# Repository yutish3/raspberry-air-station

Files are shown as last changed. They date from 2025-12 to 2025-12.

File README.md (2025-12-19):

# raspberry-air-station
this is a small project. how it overall works is raspberry pie takes data from sen 54 sensor and displayes it on e ink display and on a password protected website

deeper explanation :- it runs on a raspberry pi 4 and it uses sen 54 to get the info like (PM1.0, PM2.5, PM4.0, PM10, VOC Index, Temperature, Humidity) and display it on the e ink display which updates every 10 second and in background it is also hosting a website so you can change image on the aqi sensor like black and white art from phone and can also access the aqi data from website and the website is password protected. there is also an physical touch sensor using which you can switch between what to show on e ink display photo or the data 

i decided to make this project so i can have it as my personal home air station as i live in delhi (avg 300+ aqi) i will prob use it a lot to check the aqi and it can give an overall glimps of if i should leave the state for now or not 

# BOM
1. Sensirion SEN54 - 1 - Air Quality Sensor
2. Raspberry Pi 4 Model B (4GB RAM) - 1 - main controller
3. Waveshare 4.2-inch e-Paper Module (SPI) - 1 - display (400x300)
4. SmartElex Logic Level Converter (Bi-Directional) - 1 - 4 channel bi direction converter (3.3v - 5v)
5. Raspberry Pi 4 Power Supply (5.1V 3A Type-C) - 1 - power supply
6. Male Headers (1x40 Pin, 2.54mm) - 1
7. Female Headers (2x20 Pin, 2.54mm) - 1 
8. TTP223 Touch Sensor (Module) - 1 - input sensor
9 sd card 32 gb - 1 - for storage

i found all the components on robu except SEN54 which i found on Tanotis

# BOM images









# CAD FILE





# PCM




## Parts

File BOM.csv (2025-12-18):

part name | quantity | vendor | approx cost (inr)
raspberry pi 4 model b with 4gb ram | 1 | robu.in | 6369.00
sensirion sen55 particle & gas sensor | 1 | tanotis | 3 | 845.92
waveshare 4.2-inch e-paper module | 1 | robu.in | 2825.00
official raspberry pi micro sd card (64gb) | 1 | robu.in | 899.00
raspberry pi power adapter (5.1v 3a) | 1 | robu.in | 349.30
smartelex logic level converter (bi-directional) | 1 | robu.in | 39.00
ttp223b touch sensor | 1 | robu.in | 15.00
2.54mm 2x20 pin female header | 1 | robu.in | 10.00
custom pcb manufacturing (seeed studio) | 5 | seeed studio | $4.90
pcb shipping (dhl) | 1 | seeed studio | $28.48
robu.in | ₹ 10 | 506
tanotis.com | ₹3 | 846
seedstudio.com | $33.38

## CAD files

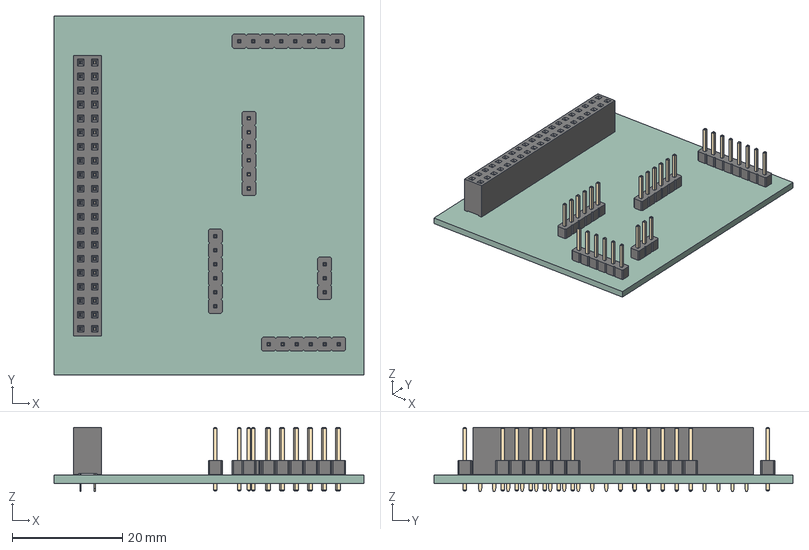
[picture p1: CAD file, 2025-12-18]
Pcb/AeroInk_HAT.step
56.1 x 65.0 x 11.6 mm
PinSocket_2x20_P2.54mm_Vertical
PinHeader_1x06_P2.54mm_Vertical x 3
PinHeader_1x08_P2.54mm_Vertical
PinHeader_1x03_P2.54mm_Vertical
AQI SEN 54_PCB

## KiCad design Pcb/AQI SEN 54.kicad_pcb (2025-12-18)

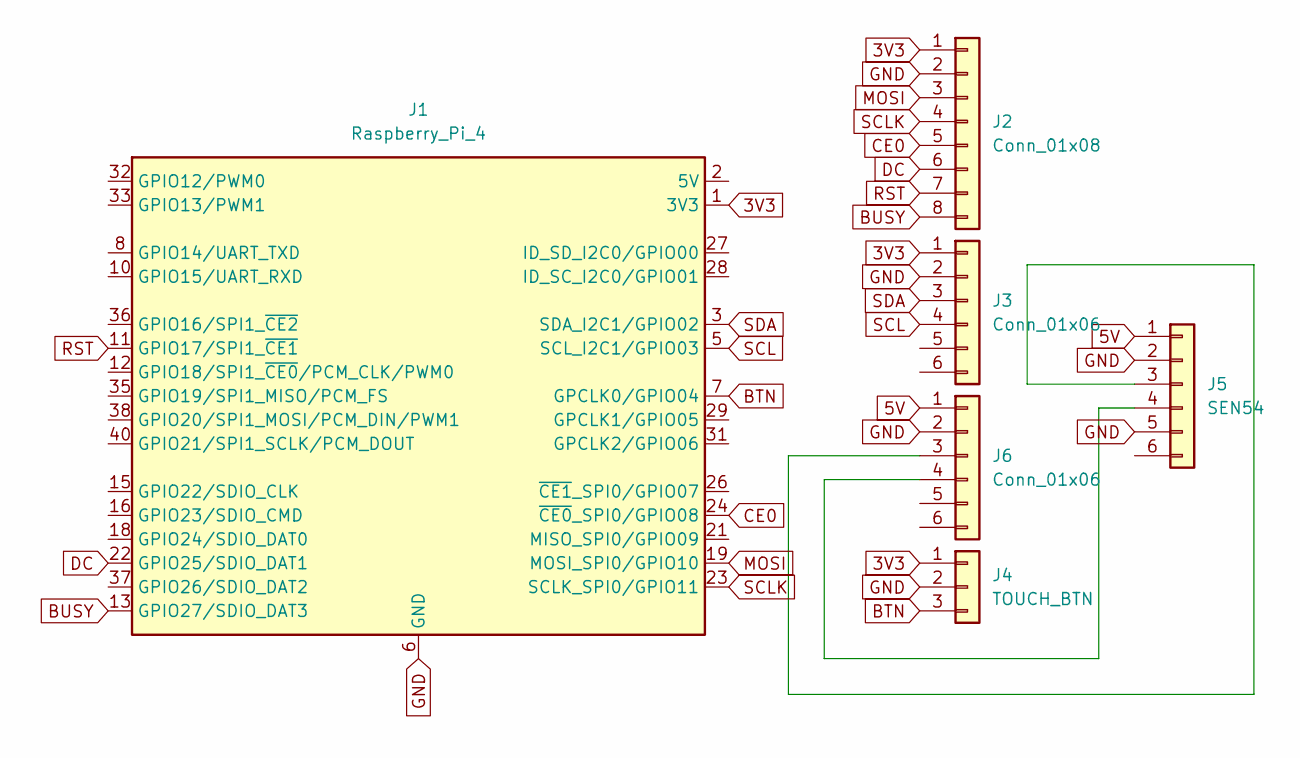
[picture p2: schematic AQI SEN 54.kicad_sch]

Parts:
J1: Raspberry_Pi_4; PinSocket_2x20_P2.54mm_Vertical
J2: Conn_01x08; PinHeader_1x08_P2.54mm_Vertical
J3, J6: Conn_01x06; PinHeader_1x06_P2.54mm_Vertical
J4: TOUCH_BTN; PinHeader_1x03_P2.54mm_Vertical
J5: SEN54; PinHeader_1x06_P2.54mm_Vertical

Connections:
3V3: J1.1 (3V3), J1.17 (3V3), J2.1, J3.1, J4.1
5V: J5.1, J6.1
BTN: J1.7 (GPCLK0/GPIO04), J4.3
BUSY: J1.13 (GPIO27/SDIO_DAT3), J2.8
CE0: J1.24 (~CE0_SPI0/GPIO08), J2.5
DC: J1.22 (GPIO25/SDIO_DAT1), J2.6
GND: J1.6 (GND), J1.9 (GND), J1.14 (GND), J1.20 (GND), J1.25 (GND), J1.30 (GND), J1.34 (GND), J1.39 (GND), J2.2, J3.2, J4.2, J5.2, J5.5, J6.2
MOSI: J1.19 (MOSI_SPI0/GPIO10), J2.3
unnamed: J1.2 (5V), J1.4 (5V)
unnamed: J5.3, J6.3
unnamed: J5.4, J6.4
RST: J1.11 (GPIO17/SPI1_~CE1), J2.7
SCL: J1.5 (SCL_I2C1/GPIO03), J3.4
SCLK: J1.23 (SCLK_SPI0/GPIO11), J2.4
SDA: J1.3 (SDA_I2C1/GPIO02), J3.3

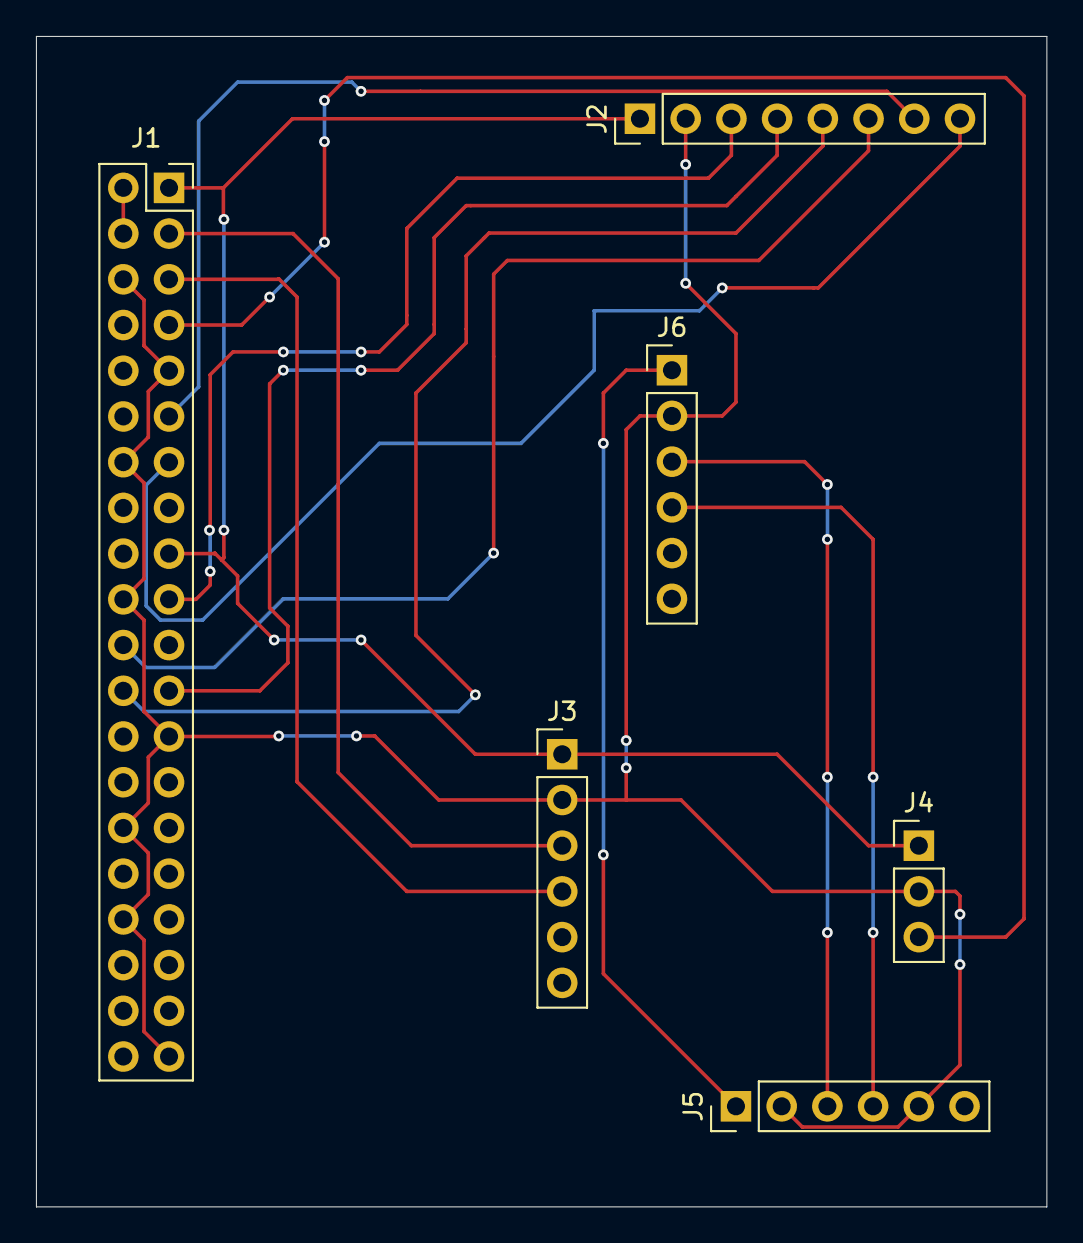
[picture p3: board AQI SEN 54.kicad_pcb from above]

Board: 2 copper layers, 56.1 x 65.0 mm, 6 parts (0 on the bottom side), 15 nets.

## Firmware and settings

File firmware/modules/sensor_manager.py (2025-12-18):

import time
import csv
import os
import threading
from datetime import datetime
try:
    from sensirion_i2c_driver import I2cConnection, LinuxI2cTransceiver
    from sensirion_i2c_sen5x import Sen5xI2cDevice
    HAS_SENSOR_LIB = True
except (ImportError, OSError):
    print("Sensor Manager: Hardware libraries not found or incompatible (Windows?). using Mock Mode.")
    HAS_SENSOR_LIB = False
    import random

from modules.config import SYSTEM_STATE, STATE_LOCK, LOG_FILE

class SensorManager(threading.Thread):
    def __init__(self):
        super().__init__()
        self.daemon = True  # kills thread when main program exits
        self.running = True
        self.i2c_transceiver = None
        self.sen54 = None
        
        # Initialize CSV
        self._init_csv()

    def _init_csv(self):
        """Creates CSV file with headers if it doesn't exist."""
        if not os.path.exists(LOG_FILE):
            with open(LOG_FILE, 'w', newline='') as f:
                writer = csv.writer(f)
                writer.writerow(["Timestamp", "PM1.0", "PM2.5", "PM4.0", "PM10", "VOC", "Temp", "Humidity"])

    def _connect_sensor(self):
        """Attempts to connect to the SEN54 sensor."""
        if not HAS_SENSOR_LIB:
            return False
            
        try:
            # On Raspberry Pi 4, the default I2C bus is usually 1
            self.i2c_transceiver = LinuxI2cTransceiver('/dev/i2c-1')
            self.sen54 = Sen5xI2cDevice(I2cConnection(self.i2c_transceiver))
            self.sen54.start_measurement()
            print("Sensor Manager: Connected to SEN54.")
            return True
        except Exception as e:
            print(f"Sensor Manager: Connection failed - {e}")
            with STATE_LOCK:
                SYSTEM_STATE["sensor_status"] = "Disconnected"
            return False

    def run(self):
        print("Sensor Manager: Thread Started")
        
        while self.running:
            if HAS_SENSOR_LIB:
                if self.sen54 is None:
                    if not self._connect_sensor():
                        time.sleep(5) 
                        self._update_mock_data() # Use mock data if connection fails
                        continue

                try:
                    # Read Data
                    data = self.sen54.read_measured_values()
                    
                    pm1_0 = data.mass_concentration_1p0.physical
                    pm2_5 = data.mass_concentration_2p5.physical
                    pm4_0 = data.mass_concentration_4p0.physical
                    pm10 = data.mass_concentration_10p0.physical
                    voc = data.voc_index.scaled
                    temp = data.ambient_temperature.degrees_celsius
                    hum = data.ambient_humidity.percent_rh
                    
                    self._update_state(pm1_0, pm2_5, pm4_0, pm10, voc, temp, hum, "Active")

                except Exception as e:
                    print(f"Sensor Manager: Read Error - {e}")
                    with STATE_LOCK:
                        SYSTEM_STATE["sensor_status"] = "Error"
                    
                    try:
                        self.i2c_transceiver.close()
                    except:
                        pass
                    self.sen54 = None
            else:
                self._update_mock_data()

            # Wait 2 seconds
            time.sleep(2)

    def _update_mock_data(self):
        """Generates fake data for testing."""
        pm1_0 = random.uniform(0, 10)
        pm2_5 = random.uniform(5, 35)
        pm4_0 = random.uniform(5, 40)
        pm10 = random.uniform(10, 50)
        voc = random.randint(50, 150)
        temp = random.uniform(20, 30)
        hum = random.uniform(40, 60)
        self._update_state(pm1_0, pm2_5, pm4_0, pm10, voc, temp, hum, "Simulated")

    def _update_state(self, pm1_0, pm2_5, pm4_0, pm10, voc, temp, hum, status):
        now = datetime.now()
        timestamp_str = now.strftime("%Y-%m-%d %H:%M:%S")

        with STATE_LOCK:
            SYSTEM_STATE["pm1_0"] = round(pm1_0, 1)
            SYSTEM_STATE["pm2_5"] = round(pm2_5, 1)
            SYSTEM_STATE["pm4_0"] = round(pm4_0, 1)
            SYSTEM_STATE["pm10"] = round(pm10, 1)
            SYSTEM_STATE["voc_index"] = round(voc, 0)
            SYSTEM_STATE["temperature"] = round(temp, 1)
            SYSTEM_STATE["humidity"] = round(hum, 1)
            SYSTEM_STATE["timestamp"] = timestamp_str
            SYSTEM_STATE["sensor_status"] = status

        # Log to CSV
        with open(LOG_FILE, 'a', newline='') as f:
            writer = csv.writer(f)
            writer.writerow([
                timestamp_str, 
                SYSTEM_STATE["pm1_0"], 
                SYSTEM_STATE["pm2_5"], 
                SYSTEM_STATE["pm4_0"], 
                SYSTEM_STATE["pm10"], 
                SYSTEM_STATE["voc_index"], 
                SYSTEM_STATE["temperature"], 
                SYSTEM_STATE["humidity"]
            ])

    def stop(self):
        self.running = False

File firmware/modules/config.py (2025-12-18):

import threading
import os

# Global State Dictionary
# This is shared between Sensor Thread, Web Thread, and Display Thread
SYSTEM_STATE = {
    "pm1_0": 0.0,
    "pm2_5": 0.0,
    "pm4_0": 0.0,
    "pm10": 0.0,
    "voc_index": 0.0,
    "temperature": 0.0,
    "humidity": 0.0,
    "timestamp": None,
    "sensor_status": "Starting..."
}

# Lock for thread-safe access to SYSTEM_STATE
STATE_LOCK = threading.Lock()

# Configuration
BASE_DIR = os.path.dirname(os.path.dirname(os.path.abspath(__file__)))
DATA_DIR = os.path.join(BASE_DIR, 'data')
LOG_FILE = os.path.join(DATA_DIR, 'sensor_log.csv')
STATIC_DIR = os.path.join(BASE_DIR, 'static')
UPLOAD_FOLDER = os.path.join(STATIC_DIR, 'uploads')
ART_IMAGE_PATH = os.path.join(UPLOAD_FOLDER, 'art.png')

# Display Configuration
# 4.2 inch e-Paper resolution is 400x300
DISPLAY_WIDTH = 400
DISPLAY_HEIGHT = 300

# Create directories if they don't exist
os.makedirs(DATA_DIR, exist_ok=True)
os.makedirs(UPLOAD_FOLDER, exist_ok=True)

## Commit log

2025-12-18 cad and pcb
    [AQI SEN 54.kicad_pcb, AQI SEN 54.kicad_sch, AeroInk_HAT.step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]
2025-12-18 Add README for raspberry-air-station project
    This README provides an overview of the raspberry-air-station project, detailing its functionality, components, and images.
2025-12-18 Add BOM images to README
    Added additional BOM images to the README.
2025-12-18 Add BOM.CSV with component details and costs
    [BOM.CSV]
2025-12-18 Create BOM.csv with component details
    Added a Bill of Materials (BOM) with parts, quantities, vendors, and costs.
    [BOM.csv]
2025-12-19 Add BOM images section to README
